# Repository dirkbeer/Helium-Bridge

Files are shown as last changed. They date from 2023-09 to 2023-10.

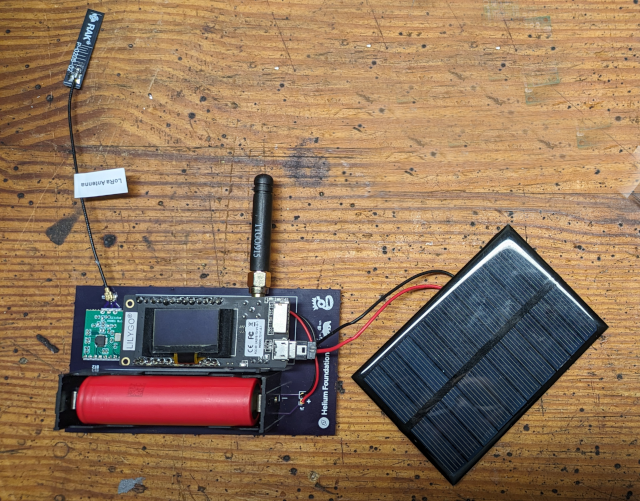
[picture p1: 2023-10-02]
_pictures/bridge.png

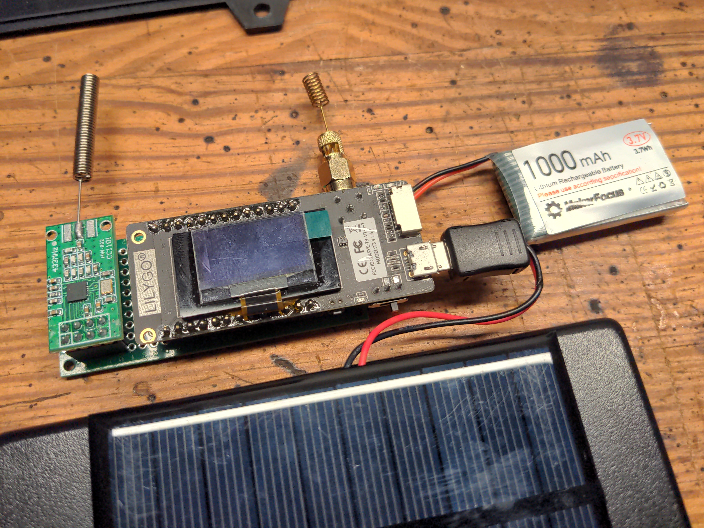
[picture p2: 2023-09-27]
_pictures/breadboard_prototype/IMG_20230515_084211_920.jpg

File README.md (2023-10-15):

### Helium Bridge

Helium Bridge is an Arduino application and printed circuit board (PCB) for ESP32 devices. It bridges data packets from sensors transmitting in the ISM bands (industrial, scientific, and medical) to LoRaWAN.

With a Helium Bridge device connecting to the Helium network,

* Off-the-shelf consumer and commercial sensors and IoT devices can be connected to the internet
* Data can be used for environmental modeling, weather dashboards, home automation, etc.
* Off-grid deployment simple since this is a compact, low power, inexpensive device 
* Many sensor devices can be relayed, and the code can be easily extended support over 100+ more
  
The Helium Bridge software and PCB design was sponsored by an innovation grant from the [Helium Foundation](https://www.helium.foundation/) to be made available open source. This work is freely available for use under its [MIT License](https://github.com/dirkbeer/Helium-Bridge/blob/main/LICENSE), copyright (c) 2023 Dirk Beer and [Gristle King, Inc](https://gristleking.com/). 



The Arduino code builds on these outstanding projects:

* [LMIC-node](https://github.com/lnlp/LMIC-node), an example LoRaWAN application for a node for The Things Network that helps get your node up and running quickly.
* [rtl_433_ESP](https://github.com/NorthernMan54/rtl_433_ESP), an Arduino library for use on ESP32 boards with a CC1101 transceiver or SX127X Transceivers with the device decoders from the rtl_433 package.
* [rtl_433](https://github.com/merbanan/rtl_433), which (despite the name) is a generic data receiver, mainly for the 433.92 MHz, 868 MHz (SRD), 315 MHz, 345 MHz, and 915 MHz ISM bands.

A version of this project with code specifically for the bridging the Ecowitt/FineOffset WS-80 Weather station to Helium, which includes some additional features and data handling for that device, is available at [Helium_Bridge_WS80](https://github.com/dirkbeer/Helium_Bridge_WS80). The PCB design is the same for both projects.

## Application
* Currently supports these 4 sensor devices (easily extended to more sensors on demand)
  * Ecowitt/Fine Offset WS-80 weather station
  * Ecowitt/Fine Offset WH-45 indoor air quality monitor
  * Acurite Tower temperature and humidity sensors
  * Springfield Soil moisture sensors
        
## Helium Bridge Device
* The bridge device can be built using our PCB board design and these components:
  * LILYGO® TTGO LoRa32 V2.1_1.6 board [link](https://www.lilygo.cc/products/lora3)
  * CC1101 RF Tranceiver Module "CC1101 868MHz" (green, squarish, no pins) [link](https://www.ebay.com/itm/311955775989)
  * 5V Polysilicon Solar Panel like this (don't use 6V panels, they may damage the Lilygo board) [link](https://www.amazon.com/gp/product/B0831CMJB9)
  * 18650 3.7V rechargeable battery
    
## Getting started
# Build a Helium Bridge device
1. Have the PCB printed: 
  * Locate the Gerber file: `Helium-Bridge/pcb/LoRaWan_Bridge_18650_CC1101SMD-Gerber.zip`
  * Order a PCB from an online service using the Gerber zip file. We used OSH Park.
  * Order a solder mask from an online services. We used OSH Stencils. When you upload the Gerber zip file there, use the layer `lorawan_bridge_18650_cc1101smd_f_paste.gbr` for the stencil.
2. In addition to the items listed above, you will need:
  * Solder paste and a method to reflow solder surface mount devices (SMDs). We used and highly recommend a DIY reflow oven like this: [link](https://whizoo.com/pages/buildguide).
  * 2.54mm pitch male and female straight single row pin headers for the Lilygo board, like the ones included in this kit [link](https://www.amazon.com/gp/product/B07CK3RCKS). You could also solder the board directly to the PCB, but it's very hard to unsolder if you run into problems.
  * A 5-Pin Micro USB Type B Male Connector for the solar panel [link](https://www.amazon.com/gp/product/B014GMP4E4)
  * An 18650 battery holder with through pins [link](https://www.digikey.com/short/39pht8dp)
  * A battery connector pigtail for connecting the Lilygo board battery input to the PCB
  * A 433MHz or 915MHz antenna with a U.FL connection
  * An SMD U.FL connector for the CC1101 antenna, like this [link](https://a.co/d/ePDIYed)
3. Use the solder mask to apply solder paste the the CC1101 and UF.L pads on the PCB, carefully place the CC1101 module and UF.L connector, and bake in the reflow oven at the temperature specified for your solder paste.
4. Once the PCB is cool, use a multimeter to test for shorts between adjacent pads of the CC1101 module and between the U.FL center pin and ground, and for good connections from pads to the module.
5. Solder the female pin headers, the battery holder, and the battery pigtail to the PCB. Pay attention to the polarity of the battery holder and pigtail.
6. Plug in the Lilygo board. To avoid damage to the devices, before you power it up, be sure to connect antennas to both the CC1101 U.FL connection and the Lilygo LoRa antenna connection.
7. Initial testing is best done without the battery or solar panel. Watch the polarity on the battery!
8. To use a solar panel, solder it to a 5-pin Micro-USB connector and plug it in to the Lilygo board.

# Run the Helium Bridge software
1. Set up a new Device on a Helium or Chirpstack Console. Edit `keyfiles/lorawan-keys_example.h` with your keys and save it as `keyfiles/lorawan-keys.h`
2. Configure the PlatformIO project. In the `platformio.ini` file, under `[env:ttgo_lora32_v21_rtl433_cc1101]` `build flags =`, specify
  * `'-DOOK_MODULATION=true' '-DRF_MODULE_FREQUENCY=433.92'` for 433MHz devices like the Acurite
  * `'-DOOK_MODULATION=false' '-DRF_MODULE_FREQUENCY=915.00'` for 915MHz devices like the Fine Offset devices
3. Upload and Monitor All using PlatformIO.
  * If LoRaWAN is working correctly, you should see the device sucessfully joining on the Helium or Chirpstack Console.
  * If the sensor decoding is working correctly, and you have one of the supported sensors up and running nearby, you should see JSON sensor data in the PlatformIO terminal
4. Use our script as the decoder Function on the Helium Console or JavaScript Codec on the Chripstack Console (it should work on both without modification)
  * Copy the content of `decoder.js` as the custom script. On Helium console, you can test the script with this example sensor data: `de7044af0a81cc`. You should see temperature and humidity. Save.
  * Connect the Function to the Device (Helium) or create an Application using the Device profile (Chripstack)
  * If everything is working, you should see data packets received in the Console, and decoded data in the Console debugger 

## Using the device
1. If desired, switch between 433MHz and 915MHz reception by sending a Downlink to the Device
  * Downlink settings should be FPort: _100_
  * On Helium Console, use payload type: _Text_. For 433MHz, send a `4`, for 915MHz, send a `9`
  * On Chirpstack Console, use payload type: _Hex_. For 433MHz, send a `34`, for 915MHz, send a `39`
2. You will have to wait for an uplink to occur, and *it may take several tries* for the downlink to be received and acted on by the bridge.
  * A limitation of LoRaWAN Class A devices like this one is that they can only receive a downlink if they have autonomously sent an uplink. You can make sure that uplinks happen periodically using `DO_WORK_INTERVAL_SECONDS` in `platformio.ini`. This is a heartbeat interval to ensure you can get a downlink command to the device even it it's not receiving & bridging any sensor packets.
  * When you are successful, the downlink will restart the device and will see JOIN requests in Console. If there are supported sensors nearby on the frequency you've switched to, you will see their data come in.

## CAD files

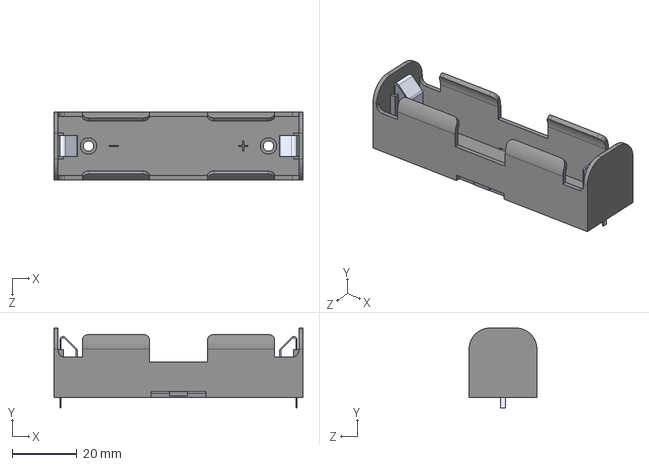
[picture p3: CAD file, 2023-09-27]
pcb/LoRaWan_Bridge_18650_CC1101SMD/BK-18650-PC2.step
77.0 x 24.7 x 21.0 mm

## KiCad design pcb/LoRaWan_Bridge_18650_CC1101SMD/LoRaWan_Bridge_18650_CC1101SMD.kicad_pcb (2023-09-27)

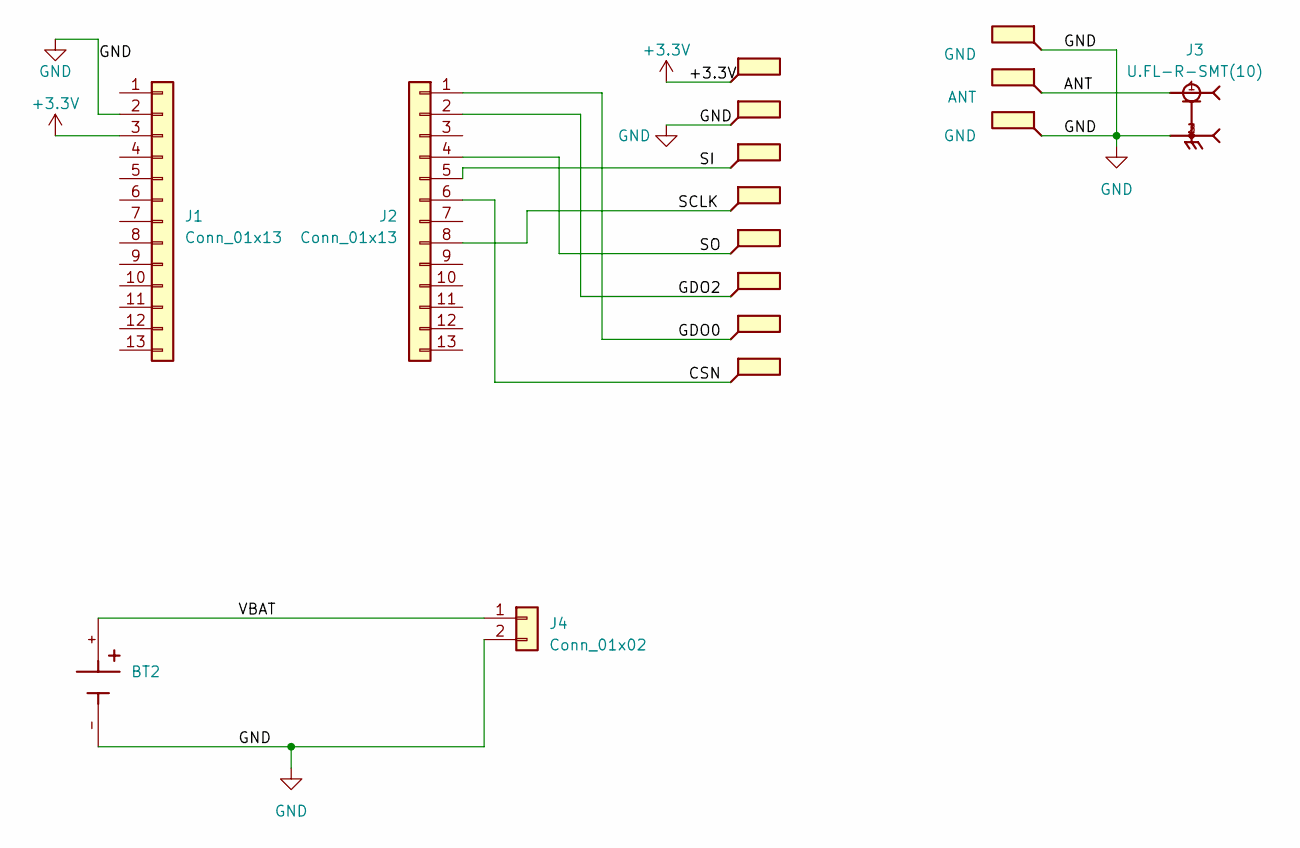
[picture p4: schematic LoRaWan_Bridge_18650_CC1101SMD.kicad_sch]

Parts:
BT2: BK-18650-PC2; BAT_BK-18650-PC2; PARTREV F
J1, J2: Conn_01x13; PinSocket_1x13_P2.54mm_Vertical
J3: U.FL-R-SMT(10); HRS_U.FL-R-SMT(10)
J4: Conn_01x02; PinSocket_1x02_P2.54mm_Vertical
P10, P12: GND; TestPoint_Pad_2.0x2.0mm
P11: ANT; TestPoint_Pad_2.0x2.0mm
TP1: VCC; TestPoint_Pad_1.2x2.0mm
TP2: GND; TestPoint_Pad_1.2x2.0mm
TP3: SI; TestPoint_Pad_1.2x2.0mm
TP4: SCLK; TestPoint_Pad_1.2x2.0mm
TP5: SO; TestPoint_Pad_1.2x2.0mm
TP6: GDO2; TestPoint_Pad_1.2x2.0mm
TP7: GDO0; TestPoint_Pad_1.2x2.0mm
TP8: CSN; TestPoint_Pad_1.2x2.0mm

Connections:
+3.3V: J1.3, TP1.1
/ANT: J3.1, P11.1
/CSN: J2.6, TP8.1
/GDO0: J2.1, TP7.1
/GDO2: J2.2, TP6.1
/SCLK: J2.8, TP4.1
/SI: J2.5, TP3.1
/SO: J2.4, TP5.1
/VBAT: BT2.+, J4.1
GND: BT2.-, J1.2, J3.2, J3.3, J4.2, P10.1, P12.1, TP2.1

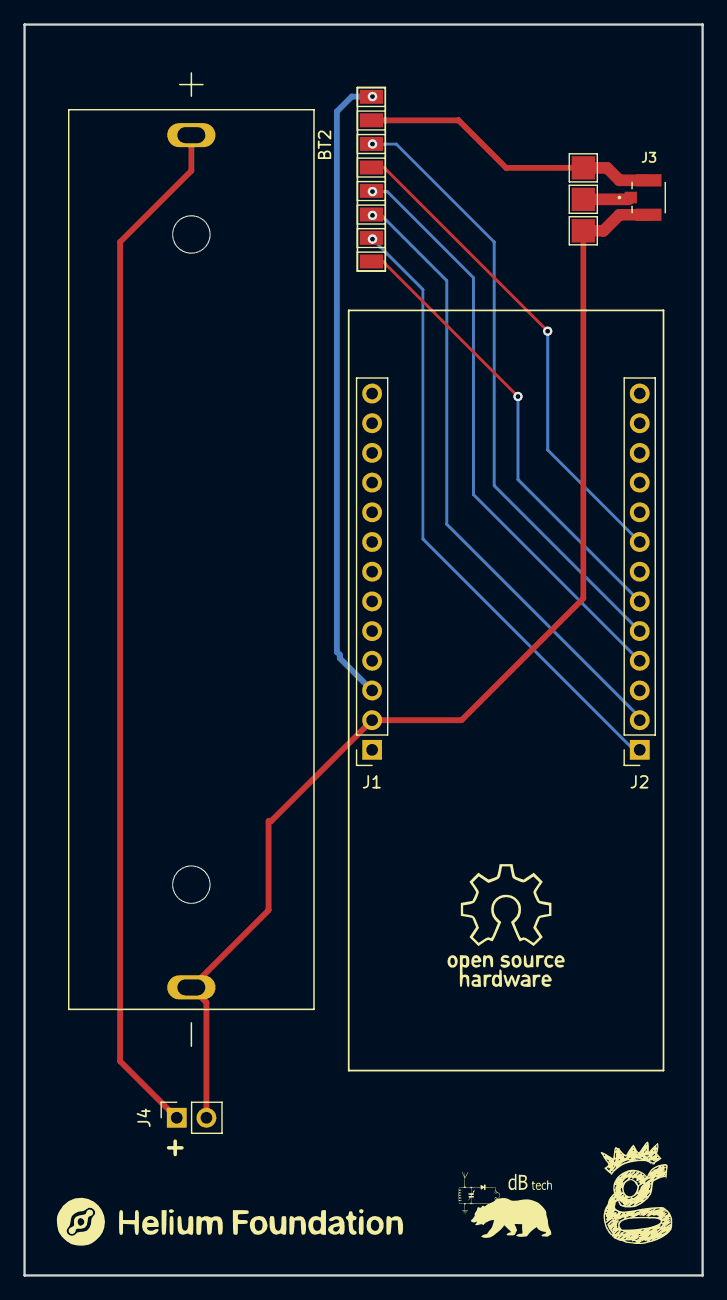
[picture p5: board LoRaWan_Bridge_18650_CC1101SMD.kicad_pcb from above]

Board: 2 copper layers, 58.0 x 107.0 mm, 16 parts (0 on the bottom side), 10 nets.

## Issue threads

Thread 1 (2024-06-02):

Raw Messages - RTL_433_ESP discussion

cgmckeever, 2024-06-02:
@dirkbeer, thanks for the updates [through the other issue](https://github.com/NorthernMan54/rtl_433_ESP/issues/104#issuecomment-2143907806) .. Taking you up on your offer - moving it here to reduce noise ;)

## Background

Let me preface, all this is brute force and learning along the way.

I was originally using [RC-Switch](https://github.com/sui77/rc-switch) to get decoded button messages. The decoded messages look like

```
Decimal: 8571080 (24Bit)
Binary: 100000101100100011001000
Tri-State: not applicable
PulseLength: 321 microseconds
Protocol: 1
```

I could then rf-transmit those back out via RC-Switch to relay/replay/etc

At the same time, I was using RTL_433_ESP to capture IOT device messages and relay them via a HTTP request to my home automation setup.

[Working code](https://github.com/cgmckeever/arduino-sketch/tree/master/esp-rf/cc1101/relay/v1)

## Problem

With the previous change to RTL_433_ESP moving the RF driver from  [SmartRC](https://github.com/LSatan/SmartRC-CC1101-Driver-Lib) to RadioLib there is a conflict with how all these pieces work.

## Hope

1. I would like to figure out if its possible to use RTL_433_esp to decode the same way RC-switch does, flagging `RTL_ANALYZER` at build gives me some results, but I cant see any correlation between the two reports. [Detail conversation of the two decodes ](https://github.com/sui77/rc-switch/issues/512)
2. Would like to use RTL_433_ESP (via RadioLib) to do the rf-transmit

I know Im talking out my ass here.

## Questions

1. In your [RTL_433_ESP fork](https://github.com/NorthernMan54/rtl_433_ESP/compare/main...dirkbeer:rtl_433_ESP:master), you do a `bytes_to_hex_string` but then it looks like you decode it `function decode(hexString)` back to a data format similar to what RTL provides -- wondering what is going on here? Im probably missing the obvious

```
const data = {
        model: 'Fineoffset-WH45',
        id: id.toString(16),
        battery_ok: batteryOk.toFixed(1),
        temperature_C: tempC.toFixed(1),
        humidity: humidity,
        pm2_5_ug_m3: pm25.toFixed(1),
        pm10_ug_m3: pm10.toFixed(1),
        co2_ppm: co2,
        ext_power: extPower,
        mic: 'CRC',
```

2. Any thoughts on using the hexstring to accomplish what Im trying to do? Literally dont know what/how to use it.

Really appreciate any ideas you might have

dirkbeer, 2024-06-10:
Hey cgmckeever,

Apologies, I wrote out a response but never sent it... see below. It's possible I didn't understand exactly what you setup is, but hopefully this info will help anyway.

Appreciate the detailed background. I'm just learning along the way here, too. Didn't realize you could compare repos like that in github, for example - very cool.

Regarding your questions,

1. The intent of the Bridge device (an ESP device, not a Raspberry Pi) is to receive sensor messages and transmit them onto the Helium LoRaWAN network. Once there, a LoRaWAN Network Server (I'm using the meteoscientific.com ChirpStack LNS) decodes the message and makes it available via various integrations (http, mqtt) to consumers like home assistant.

The decoder.js  function decode(hexString) is not run on the Bridge, but later on the LNS so that that can provide the plain text decoded data to the user.

The Bridge just keeps the data in hex format. It receives the sensor messages using RTL_433_ESP, and then retransmits them using LoRaWAN using LMIC_node. The hex format keeps the LoRaWAN packet sizes small.

It makes sense to use RadioLib to retransmit the data (instead of LMIC like I do), but I'm not familiar enough with RadioLib to help with that aspect. (LMIC is exclusively LoRaWAN, which is not what you want.)

2. For you to use rtl_433 (on Raspberry Pi), the button message you want to retransmit would have to be from one of the devices it supports

Is your device on that list? If it is, you should be able to get a read-out similar to what you get with RC-Switch. (to make things easier, you could test with rtl_433, which you can install on a raspberry pi or any linux machine)

Once you confirm that rlt_433 and RTL_433_ESP can read the message, you could modify that sensor's decoder function in [rtl_433_ESP/src/rtl_433/devices at main · NorthernMan54/rtl_433_ESP (github.com)](https://github.com/NorthernMan54/rtl_433_ESP/tree/main/src/rtl_433/devices).

However, it sounds like you are trying to retransmit an RC remote control signal, and I don't think rlt_433 will decode those. Also rtl_433 and RTL_433_ESP code only receives, it doesn't retransmit.

It sounds like you are on Raspberry Pi, so I think what makes most sense it to receive and decode using RC-Switch like you are now, convert the binary "100000101100100011001000" data to hex, and then figure out how to retransmit using RadioLib.

Let me know if this helps at all.

Cheers,
Dirk

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

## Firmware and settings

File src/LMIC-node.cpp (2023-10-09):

/*******************************************************************************
 *
 *  File:          LMIC-node.cpp
 * 
 *  Function:      LMIC-node main application file.
 * 
 *  Copyright:     Copyright (c) 2021 Leonel Lopes Parente
 *                 Copyright (c) 2018 Terry Moore, MCCI
 *                 Copyright (c) 2015 Thomas Telkamp and Matthijs Kooijman
 *
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
 *                 THE SOFTWARE IS PROVIDED "AS IS", WITHOUT ANY WARRANTY.
 * 
 *  License:       MIT License. See accompanying LICENSE file.
 * 
 *  Author:        Leonel Lopes Parente
 * 
 *  Description:   To get LMIC-node up and running no changes need to be made
 *                 to any source code. Only configuration is required
 *                 in platform-io.ini and lorawan-keys.h.
 * 
 *                 If you want to modify the code e.g. to add your own sensors,
 *                 that can be done in the two area's that start with
 *                 USER CODE BEGIN and end with USER CODE END. There's no need
 *                 to change code in other locations (unless you have a reason).
 *                 See README.md for documentation and how to use LMIC-node.
 * 
 *                 LMIC-node uses the concepts from the original ttn-otaa.ino 
 *                 and ttn-abp.ino examples provided with the LMIC libraries.
 *                 LMIC-node combines both OTAA and ABP support in a single example,
 *                 supports multiple LMIC libraries, contains several improvements
 *                 and enhancements like display support, support for downlinks,
 *                 separates LoRaWAN keys from source code into a separate keyfile,
 *                 provides formatted output to serial port and display
 *                 and supports many popular development boards out of the box.
 *                 To get a working node up and running only requires some configuration.
 *                 No programming or customization of source code required.
 * 
 *  Dependencies:  External libraries:
 *                 MCCI LoRaWAN LMIC library  https://github.com/mcci-catena/arduino-lmic
 *                 IBM LMIC framework         https://github.com/matthijskooijman/arduino-lmic  
 *                 U8g2                       https://github.com/olikraus/u8g2
 *                 EasyLed                    https://github.com/lnlp/EasyLed
 *
 ******************************************************************************/

#include "LMIC-node.h"

//  █ █ █▀▀ █▀▀ █▀▄   █▀▀ █▀█ █▀▄ █▀▀   █▀▄ █▀▀ █▀▀ ▀█▀ █▀█
//  █ █ ▀▀█ █▀▀ █▀▄   █   █ █ █ █ █▀▀   █▀▄ █▀▀ █ █  █  █ █
//  ▀▀▀ ▀▀▀ ▀▀▀ ▀ ▀   ▀▀▀ ▀▀▀ ▀▀  ▀▀▀   ▀▀  ▀▀▀ ▀▀▀ ▀▀▀ ▀ ▀
#include "EEPROM.h"
  #define DEMODMODECMD_ADDR 0x00
  #define DEMODMODE_FSK915 0x01
  #define DEMODMODE_OOK433 0x02
  #define DEMODMODE_UNKNOWN 0x00

const uint8_t payloadBufferLength = 4;    // Adjust to fit max payload length

/*
 Basic rtl_433_ESP example for OOK/ASK Devices

*/

#include <ArduinoJson.h>
#include <ArduinoLog.h>
#include <rtl_433_ESP.h>

#ifndef RF_MODULE_FREQUENCY
#  define RF_MODULE_FREQUENCY 433.92
#endif

#define JSON_MSG_BUFFER 512
#define RAW_MSG_BUFFER 64

char messageBuffer[JSON_MSG_BUFFER];
uint8_t rawBuffer[RAW_MSG_BUFFER];
size_t actualBufferSize;
volatile bool sendUplinkFlag = false;
unsigned long lastSendTime = 0;  // Variable to store the last time sendUplink() was executed
unsigned long quietTime = 4500;  // time to wait before repeating another data packet in milliseconds

rtl_433_ESP rf; // use -1 to disable transmitter

void logJson(JsonObject& jsondata) {
#if defined(ESP8266) || defined(ESP32) || defined(__AVR_ATmega2560__) || defined(__AVR_ATmega1280__)
  char JSONmessageBuffer[jsondata.measureLength() + 1];
#else
  char JSONmessageBuffer[JSON_MSG_BUFFER];
#endif
  jsondata.printTo(JSONmessageBuffer, sizeof(JSONmessageBuffer));
#if defined(setBitrate) || defined(setFreqDev) || defined(setRxBW)
  Log.setShowLevel(false);
  Log.notice(F("."));
  Log.setShowLevel(true);
#else
  Log.notice(F("Received message : %s" CR), JSONmessageBuffer);
#endif
}

uint8_t hexCharToByte(char c) {
    if (c >= '0' && c <= '9') return c - '0';
    if (c >= 'a' && c <= 'f') return c - 'a' + 10;
    if (c >= 'A' && c <= 'F') return c - 'A' + 10;
    return 0; // Invalid input
}

bool getRawBytes(JsonObject& jsondata, uint8_t* rawBuffer, size_t maxArraySize, size_t* actualArraySize) {
    if (jsondata.containsKey("raw_bytes")) {
        const char* rawBytes = jsondata["raw_bytes"];
        size_t len = strlen(rawBytes);
        if (len % 2 != 0 || len / 2 > maxArraySize) return false; // Invalid input or insufficient array size

        *actualArraySize = len / 2;

        for (size_t i = 0, j = 0; i < len; i += 2, j++) {
            char c1 = rawBytes[i];
            char c2 = rawBytes[i + 1];
            rawBuffer[j] = (hexCharToByte(c1) << 4) + hexCharToByte(c2);
        }

        return true;
    } else {
        *actualArraySize = 0;
        return false;
    }
}

void rtl_433_Callback(char* message) {
  DynamicJsonBuffer jsonBuffer2(JSON_MSG_BUFFER);
  JsonObject& RFrtl_433_ESPdata = jsonBuffer2.parseObject(message);
  logJson(RFrtl_433_ESPdata);
 
  if (getRawBytes(RFrtl_433_ESPdata, rawBuffer, RAW_MSG_BUFFER, &actualBufferSize)) 
  {
      // Successfully converted, use rawBuffer and actualArraySize
      Serial.print("Array of size ");
      Serial.print(actualBufferSize);
      Serial.println(" found.");
      sendUplinkFlag = true;
  } else {
      // "raw_bytes" was not found in the JSON object
      Serial.println("raw_bytes not found");
  }
}

//  █ █ █▀▀ █▀▀ █▀▄   █▀▀ █▀█ █▀▄ █▀▀   █▀▀ █▀█ █▀▄
//  █ █ ▀▀█ █▀▀ █▀▄   █   █ █ █ █ █▀▀   █▀▀ █ █ █ █
//  ▀▀▀ ▀▀▀ ▀▀▀ ▀ ▀   ▀▀▀ ▀▀▀ ▀▀  ▀▀▀   ▀▀▀ ▀ ▀ ▀▀ 


uint8_t payloadBuffer[payloadBufferLength];
static osjob_t doWorkJob;
uint32_t doWorkIntervalSeconds = DO_WORK_INTERVAL_SECONDS;  // Change value in platformio.ini

// Note: LoRa module pin mappings are defined in the Board Support Files.

// Set LoRaWAN keys defined in lorawan-keys.h.
#ifdef OTAA_ACTIVATION
    static const u1_t PROGMEM DEVEUI[8]  = { OTAA_DEVEUI } ;
    static const u1_t PROGMEM APPEUI[8]  = { OTAA_APPEUI };
    static const u1_t PROGMEM APPKEY[16] = { OTAA_APPKEY };
    // Below callbacks are used by LMIC for reading above values.
    void os_getDevEui (u1_t* buf) { memcpy_P(buf, DEVEUI, 8); }
    void os_getArtEui (u1_t* buf) { memcpy_P(buf, APPEUI, 8); }
    void os_getDevKey (u1_t* buf) { memcpy_P(buf, APPKEY, 16); }    
#else
    // ABP activation
    static const u4_t DEVADDR = ABP_DEVADDR ;
    static const PROGMEM u1_t NWKSKEY[16] = { ABP_NWKSKEY };
    static const u1_t PROGMEM APPSKEY[16] = { ABP_APPSKEY };
    // Below callbacks are not used be they must be defined.
    void os_getDevEui (u1_t* buf) { }
    void os_getArtEui (u1_t* buf) { }
    void os_getDevKey (u1_t* buf) { }
#endif


int16_t getSnrTenfold()
{
    // Returns ten times the SNR (dB) value of the last received packet.
    // Ten times to prevent the use of float but keep 1 decimal digit accuracy.
    // Calculation per SX1276 datasheet rev.7 §6.4, SX1276 datasheet rev.4 §6.4.
    // LMIC.snr contains value of PacketSnr, which is 4 times the actual SNR value.
    return (LMIC.snr * 10) / 4;
}


int16_t getRssi(int8_t snr)
{
    // Returns correct RSSI (dBm) value of the last received packet.
    // Calculation per SX1276 datasheet rev.7 §5.5.5, SX1272 datasheet rev.4 §5.5.5.

    #define RSSI_OFFSET            64
    #define SX1276_FREQ_LF_MAX     525000000     // per datasheet 6.3
    #define SX1272_RSSI_ADJUST     -139
    #define SX1276_RSSI_ADJUST_LF  -164
    #define SX1276_RSSI_ADJUST_HF  -157

    int16_t rssi;

    #ifdef MCCI_LMIC

        rssi = LMIC.rssi - RSSI_OFFSET;

    #else
        int16_t rssiAdjust;
        #ifdef CFG_sx1276_radio
            if (LMIC.freq > SX1276_FREQ_LF_MAX)
            {
                rssiAdjust = SX1276_RSSI_ADJUST_HF;
            }
            else
            {
                rssiAdjust = SX1276_RSSI_ADJUST_LF;   
            }
        #else
            // CFG_sx1272_radio    
            rssiAdjust = SX1272_RSSI_ADJUST;
        #endif    
        
        // Revert modification (applied in lmic/radio.c) to get PacketRssi.
        int16_t packetRssi = LMIC.rssi + 125 - RSSI_OFFSET;
        if (snr < 0)
        {
            rssi = rssiAdjust + packetRssi + snr;
        }
        else
        {
            rssi = rssiAdjust + (16 * packetRssi) / 15;
        }
    #endif

    return rssi;
}


void printEvent(ostime_t timestamp, 
                const char * const message, 
                PrintTarget target = PrintTarget::All,
                bool clearDisplayStatusRow = true,
                bool eventLabel = false)
{
    #ifdef USE_DISPLAY 
        if (target == PrintTarget::All || target == PrintTarget::Display)
        {
            display.clearLine(TIME_ROW);
            display.setCursor(COL_0, TIME_ROW);
            display.print(F("Time:"));                 
            display.print(timestamp); 
            display.clearLine(EVENT_ROW);
            if (clearDisplayStatusRow)
            {
                display.clearLine(STATUS_ROW);    
            }
            display.setCursor(COL_0, EVENT_ROW);               
            display.print(message);
        }
    #endif  
    
    #ifdef USE_SERIAL
        // Create padded/indented output without using printf().
        // printf() is not default supported/enabled in each Arduino core. 
        // Not using printf() will save memory for memory constrainted devices.
        String timeString(timestamp);
        uint8_t len = timeString.length();
        uint8_t zerosCount = TIMESTAMP_WIDTH > len ? TIMESTAMP_WIDTH - len : 0;

        if (target == PrintTarget::All || target == PrintTarget::Serial)
        {
            printChars(serial, '0', zerosCount);
            serial.print(timeString);
            serial.print(":  ");
            if (eventLabel)
            {
                serial.print(F("Event: "));
            }
            serial.println(message);
        }
    #endif   
}           

void printEvent(ostime_t timestamp, 
                ev_t ev, 
                PrintTarget target = PrintTarget::All, 
                bool clearDisplayStatusRow = true)
{
    #if defined(USE_DISPLAY) || defined(USE_SERIAL)
        printEvent(timestamp, lmicEventNames[ev], target, clearDisplayStatusRow, true);
    #endif
}


void printFrameCounters(PrintTarget target = PrintTarget::All)
{
    #ifdef USE_DISPLAY
        if (target == PrintTarget::Display || target == PrintTarget::All)
        {
            display.clearLine(FRMCNTRS_ROW);
            display.setCursor(COL_0, FRMCNTRS_ROW);
            display.print(F("Up:"));
            display.print(LMIC.seqnoUp);
            display.print(F(" Dn:"));
            display.print(LMIC.seqnoDn);        
        }
    #endif

    #ifdef USE_SERIAL
        if (target == PrintTarget::Serial || target == PrintTarget::All)
        {
            printSpaces(serial, MESSAGE_INDENT);
            serial.print(F("Up: "));
            serial.print(LMIC.seqnoUp);
            serial.print(F(",  Down: "));
            serial.println(LMIC.seqnoDn);        
        }
    #endif        
}      


void printSessionKeys()
{    
    #if defined(USE_SERIAL) && defined(MCCI_LMIC)
        u4_t networkId = 0;
        devaddr_t deviceAddress = 0;
        u1_t networkSessionKey[16];
        u1_t applicationSessionKey[16];
        LMIC_getSessionKeys(&networkId, &deviceAddress, 
                            networkSessionKey, applicationSessionKey);

        printSpaces(serial, MESSAGE_INDENT);    
        serial.print(F("Network Id: "));
        serial.println(networkId, DEC);

        printSpaces(serial, MESSAGE_INDENT);    
        serial.print(F("Device Address: "));
        serial.println(deviceAddress, HEX);

        printSpaces(serial, MESSAGE_INDENT);    
        serial.print(F("Application Session Key: "));
        printHex(serial, applicationSessionKey, 16, true, '-');

        printSpaces(serial, MESSAGE_INDENT);    
        serial.print(F("Network Session Key:     "));
        printHex(serial, networkSessionKey, 16, true, '-');
    #endif
}


void printDownlinkInfo(void)
{
    #if defined(USE_SERIAL) || defined(USE_DISPLAY)

        uint8_t dataLength = LMIC.dataLen;
        // bool ackReceived = LMIC.txrxFlags & TXRX_ACK;

        int16_t snrTenfold = getSnrTenfold();
        int8_t snr = snrTenfold / 10;
        int8_t snrDecimalFraction = snrTenfold % 10;
        int16_t rssi = getRssi(snr);

        uint8_t fPort = 0;        
        if (LMIC.txrxFlags & TXRX_PORT)
        {
            fPort = LMIC.frame[LMIC.dataBeg -1];
        }        

        #ifdef USE_DISPLAY
            display.clearLine(EVENT_ROW);        
            display.setCursor(COL_0, EVENT_ROW);
            display.print(F("RX P:"));
            display.print(fPort);
            if (dataLength != 0)
            {
                display.print(" Len:");
                display.print(LMIC.dataLen);                       
            }
            display.clearLine(STATUS_ROW);        
            display.setCursor(COL_0, STATUS_ROW);
            display.print(F("RSSI"));
            display.print(rssi);
            display.print(F(" SNR"));
            display.print(snr);                
            display.print(".");                
            display.print(snrDecimalFraction);                      
        #endif

        #ifdef USE_SERIAL
            printSpaces(serial, MESSAGE_INDENT);    
            serial.println(F("Downlink received"));

            printSpaces(serial, MESSAGE_INDENT);
            serial.print(F("RSSI: "));
            serial.print(rssi);
            serial.print(F(" dBm,  SNR: "));
            serial.print(snr);                        
            serial.print(".");                        
            serial.print(snrDecimalFraction);                        
            serial.println(F(" dB"));

            printSpaces(serial, MESSAGE_INDENT);    
            serial.print(F("Port: "));
            serial.println(fPort);
   
            if (dataLength != 0)
            {
                printSpaces(serial, MESSAGE_INDENT);
                serial.print(F("Length: "));
                serial.println(LMIC.dataLen);                   
                printSpaces(serial, MESSAGE_INDENT);    
                serial.print(F("Data: "));
                printHex(serial, LMIC.frame+LMIC.dataBeg, LMIC.dataLen, true, ' ');
            }
        #endif
    #endif
} 


void printHeader(void)
{
    #ifdef USE_DISPLAY
        display.clear();
        display.setCursor(COL_0, HEADER_ROW);
        display.print(F("LMIC-node"));
        #ifdef ABP_ACTIVATION
            display.drawString(ABPMODE_COL, HEADER_ROW, "ABP");
        #endif
        #ifdef CLASSIC_LMIC
            display.drawString(CLMICSYMBOL_COL, HEADER_ROW, "*");
        #endif
        display.drawString(COL_0, DEVICEID_ROW, deviceId);
        display.setCursor(COL_0, INTERVAL_ROW);
        display.print(F("Interval:"));
        display.print(doWorkIntervalSeconds);
        display.print("s");
    #endif

    #ifdef USE_SERIAL
        serial.println(F("\n\nLMIC-node\n"));
        serial.print(F("Device-id:     "));
        serial.println(deviceId);            
        serial.print(F("LMIC library:  "));
        #ifdef MCCI_LMIC  
            serial.println(F("MCCI"));
        #else
            serial.println(F("Classic [Deprecated]")); 
        #endif
        serial.print(F("Activation:    "));
        #ifdef OTAA_ACTIVATION  
            serial.println(F("OTAA"));
        #else
            serial.println(F("ABP")); 
        #endif
        #if defined(LMIC_DEBUG_LEVEL) && LMIC_DEBUG_LEVEL > 0
            serial.print(F("LMIC debug:    "));  
            serial.println(LMIC_DEBUG_LEVEL);
        #endif
        serial.print(F("Interval:      "));
        serial.print(doWorkIntervalSeconds);
        serial.println(F(" seconds"));
        if (activationMode == ActivationMode::OTAA)
        {
            serial.println();
        }
    #endif
}     


#ifdef ABP_ACTIVATION
    void setAbpParameters(dr_t dataRate = DefaultABPDataRate, s1_t txPower = DefaultABPTxPower) 
    {
        // Set static session parameters. Instead of dynamically establishing a session
        // by joining the network, precomputed session parameters are be provided.
        #ifdef PROGMEM
            // On AVR, these values are stored in flash and only copied to RAM
            // once. Copy them to a temporary buffer here, LMIC_setSession will
            // copy them into a buffer of its own again.
            uint8_t appskey[sizeof(APPSKEY)];
            uint8_t nwkskey[sizeof(NWKSKEY)];
            memcpy_P(appskey, APPSKEY, sizeof(APPSKEY));
            memcpy_P(nwkskey, NWKSKEY, sizeof(NWKSKEY));
            LMIC_setSession (0x1, DEVADDR, nwkskey, appskey);
        #else
            // If not running an AVR with PROGMEM, just use the arrays directly
            LMIC_setSession (0x1, DEVADDR, NWKSKEY, APPSKEY);
        #endif

        #if defined(CFG_eu868)
            // Set up the channels used by the Things Network, which corresponds
            // to the defaults of most gateways. Without this, only three base
            // channels from the LoRaWAN specification are used, which certainly
            // works, so it is good for debugging, but can overload those
            // frequencies, so be sure to configure the full frequency range of
            // your network here (unless your network autoconfigures them).
            // Setting up channels should happen after LMIC_setSession, as that
            // configures the minimal channel set. The LMIC doesn't let you change
            // the three basic settings, but we show them here.
            LMIC_setupChannel(0, 868100000, DR_RANGE_MAP(DR_SF12, DR_SF7),  BAND_CENTI);      // g-band
            LMIC_setupChannel(1, 868300000, DR_RANGE_MAP(DR_SF12, DR_SF7B), BAND_CENTI);      // g-band
            LMIC_setupChannel(2, 868500000, DR_RANGE_MAP(DR_SF12, DR_SF7),  BAND_CENTI);      // g-band
            LMIC_setupChannel(3, 867100000, DR_RANGE_MAP(DR_SF12, DR_SF7),  BAND_CENTI);      // g-band
            LMIC_setupChannel(4, 867300000, DR_RANGE_MAP(DR_SF12, DR_SF7),  BAND_CENTI);      // g-band
            LMIC_setupChannel(5, 867500000, DR_RANGE_MAP(DR_SF12, DR_SF7),  BAND_CENTI);      // g-band
            LMIC_setupChannel(6, 867700000, DR_RANGE_MAP(DR_SF12, DR_SF7),  BAND_CENTI);      // g-band
            LMIC_setupChannel(7, 867900000, DR_RANGE_MAP(DR_SF12, DR_SF7),  BAND_CENTI);      // g-band
            LMIC_setupChannel(8, 868800000, DR_RANGE_MAP(DR_FSK,  DR_FSK),  BAND_MILLI);      // g2-band
            // TTN defines an additional channel at 869.525Mhz using SF9 for class B
            // devices' ping slots. LMIC does not have an easy way to define set this
            // frequency and support for class B is spotty and untested, so this
            // frequency is not configured here.
        #elif defined(CFG_us915) || defined(CFG_au915)
            // NA-US and AU channels 0-71 are configured automatically
            // but only one group of 8 should (a subband) should be active
            // TTN recommends the second sub band, 1 in a zero based count.
            // https://github.com/TheThingsNetwork/gateway-conf/blob/master/US-global_conf.json
            LMIC_selectSubBand(1);
        #elif defined(CFG_as923)
            // Set up the channels used in your country. Only two are defined by default,
            // and they cannot be changed.  Use BAND_CENTI to indicate 1% duty cycle.
            // LMIC_setupChannel(0, 923200000, DR_RANGE_MAP(DR_SF12, DR_SF7),  BAND_CENTI);
            // LMIC_setupChannel(1, 923400000, DR_RANGE_MAP(DR_SF12, DR_SF7),  BAND_CENTI);

            // ... extra definitions for channels 2..n here
        #elif defined(CFG_kr920)
            // Set up the channels used in your country. Three are defined by default,
            // and they cannot be changed. Duty cycle doesn't matter, but is conventionally
            // BAND_MILLI.
            // LMIC_setupChannel(0, 922100000, DR_RANGE_MAP(DR_SF12, DR_SF7),  BAND_MILLI);
            // LMIC_setupChannel(1, 922300000, DR_RANGE_MAP(DR_SF12, DR_SF7),  BAND_MILLI);
            // LMIC_setupChannel(2, 922500000, DR_RANGE_MAP(DR_SF12, DR_SF7),  BAND_MILLI);

            // ... extra definitions for channels 3..n here.
        #elif defined(CFG_in866)
            // Set up the channels used in your country. Three are defined by default,
            // and they cannot be changed. Duty cycle doesn't matter, but is conventionally
            // BAND_MILLI.
            // LMIC_setupChannel(0, 865062500, DR_RANGE_MAP(DR_SF12, DR_SF7),  BAND_MILLI);
            // LMIC_setupChannel(1, 865402500, DR_RANGE_MAP(DR_SF12, DR_SF7),  BAND_MILLI);
            // LMIC_setupChannel(2, 865985000, DR_RANGE_MAP(DR_SF12, DR_SF7),  BAND_MILLI);

            // ... extra definitions for channels 3..n here.
        #endif

        // Disable link check validation
        LMIC_setLinkCheckMode(0);

        // TTN uses SF9 for its RX2 window.
        LMIC.dn2Dr = DR_SF9;

        // Set data rate and transmit power (note: txpow is possibly ignored by the library)
        LMIC_setDrTxpow(dataRate, txPower);    
    }
#endif //ABP_ACTIVATION
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
void loop() 
{

    rf.loop();

    unsigned long currentTime = millis();  // Get the current time

    // Check if sendUplinkFlag is set and if enough time has passed since the last sendUplink() call
    if (sendUplinkFlag && (currentTime - lastSendTime >= quietTime)) {
        sendUplinkFlag = false;
        sendUplink(rawBuffer, actualBufferSize);
        lastSendTime = currentTime;  // Update the last send time
    }
    
    os_runloop_once();

}

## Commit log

2023-10-06 springfield decoder fix
2023-10-09 downlink & mode switch debugging
2023-10-15 Add Gerber
2023-10-15 fix gerber name
2023-10-15 add drill files to gerber
    [LoRaWan_Bridge_18650_CC1101SMD-NPTH.drl, LoRaWan_Bridge_18650_CC1101SMD-PTH.drl]
